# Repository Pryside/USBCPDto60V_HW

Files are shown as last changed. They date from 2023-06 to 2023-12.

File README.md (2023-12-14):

# USBCPDto60V_HW
the hardware portion of the USBC-PD Project

Software here: https://github.com/Pryside/USBCPDto60V

KiCad Project Files

Note: This is just a development Board, not the finished product. For testing purposes.

Done:
- ADC Voltage Measurement
- ADC Bi-Dir Current Measurement
- HRTimer D
- HRTimer C
- Full Bi-Directional Converter

To Do:
- Lower Noise on ADCs
- double check new Timer Routing
- Update ADC channel inputs
  


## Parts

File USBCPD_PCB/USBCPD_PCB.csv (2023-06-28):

# | Reference | Qty | Value | Footprint | DNP
1 | C1 | 1 | 1uF 25V | Capacitor_SMD:C_0603_1608Metric_Pad1.08x0.95mm_HandSolder
2 | C2 | 1 | A768MS277M1VLAS022 | CAPAE1030X1270N
3 | C3, C5, C6, C7 | 4 | GRM32DL8EL475KE07K | CAPC3225X220N
4 | C4 | 1 | 0.33uF 25V | Capacitor_SMD:C_0603_1608Metric_Pad1.08x0.95mm_HandSolder
5 | C8 | 1 | EEE-TP1K391M | EEEFK0J682AM
6 | C9, C12, C13, C16 | 4 | 1nF 25V | Capacitor_SMD:C_0402_1005Metric_Pad0.74x0.62mm_HandSolder
7 | C10, C14 | 2 | 4.7uF 25V | Capacitor_SMD:C_0603_1608Metric_Pad1.08x0.95mm_HandSolder
8 | C11, C15 | 2 | 0.1uF 25V | Capacitor_SMD:C_0603_1608Metric_Pad1.08x0.95mm_HandSolder
9 | D1 | 1 | T4F24AHM3_I | SODFL3718X108N
10 | D2 | 1 | 1.5SMBJ51CA-H | DIONM5436X244N
11 | IC1 | 1 | TMCS1108A3BQDRQ1 | SOIC127P600X175-8N
12 | IC2, IC3 | 2 | UCC27282QDRQ1 | SOIC127P600X175-8N
13 | IC4 | 1 | BAJ2CC0FP-E2 | BD750L5FPCE2
14 | J1, J2 | 2 | TB002-500-02BE | TB00250002BE
15 | JP1 | 1 | SolderJumper_2_Bridged | Jumper:SolderJumper-2_P1.3mm_Bridged_RoundedPad1.0x1.5mm
16 | L1 | 1 | SRP1038WA-150M | SRP1038WA150M
17 | LED1 | 1 | 150060BS75003 | 150060BS75003
18 | LED2 | 1 | 150060GS75003 | LEDC1608X80N
19 | LED3 | 1 | 150060SS75003 | 150060SS75003
20 | Q1, Q2, Q3, Q4 | 4 | SIR584DP-T1-RE3 | SamacSys_Parts:SIR584DPT1RE3
21 | R1, R2, R5, R6, R7 | 5 | 1R | Resistor_SMD:R_0603_1608Metric_Pad0.98x0.95mm_HandSolder
22 | R3, R4, R12, R15 | 4 | 3R | Resistor_SMD:R_0603_1608Metric_Pad0.98x0.95mm_HandSolder
23 | R8 | 1 | 100R | Resistor_SMD:R_0603_1608Metric_Pad0.98x0.95mm_HandSolder | DNP
24 | R9 | 1 | 900R | Resistor_SMD:R_0603_1608Metric_Pad0.98x0.95mm_HandSolder
25 | R10 | 1 | 2.8K | Resistor_SMD:R_0603_1608Metric_Pad0.98x0.95mm_HandSolder
26 | R11 | 1 | 100R | Resistor_SMD:R_0603_1608Metric_Pad0.98x0.95mm_HandSolder
27 | R13 | 1 | 28K | Resistor_SMD:R_0603_1608Metric_Pad0.98x0.95mm_HandSolder
28 | R14 | 1 | 1K62 | Resistor_SMD:R_0603_1608Metric_Pad0.98x0.95mm_HandSolder
29 | S1 | 1 | EVP-BDCC1A000 | EVPBDCC1A000
30 | TP1, TP2, TP3, TP4, TP5, TP6, TP7, TP8, TP9, TP10 | 10 | TestPoint | TestPoint:TestPoint_Pad_D1.0mm
31 | U1 | 1 | NUCLEO-G474RE | USBC_PD:ST_NUCLEO-G474RE
32 | Z1, Z2, Z3, Z4 | 4 | PDZ15B,115 | SOD2512X110N

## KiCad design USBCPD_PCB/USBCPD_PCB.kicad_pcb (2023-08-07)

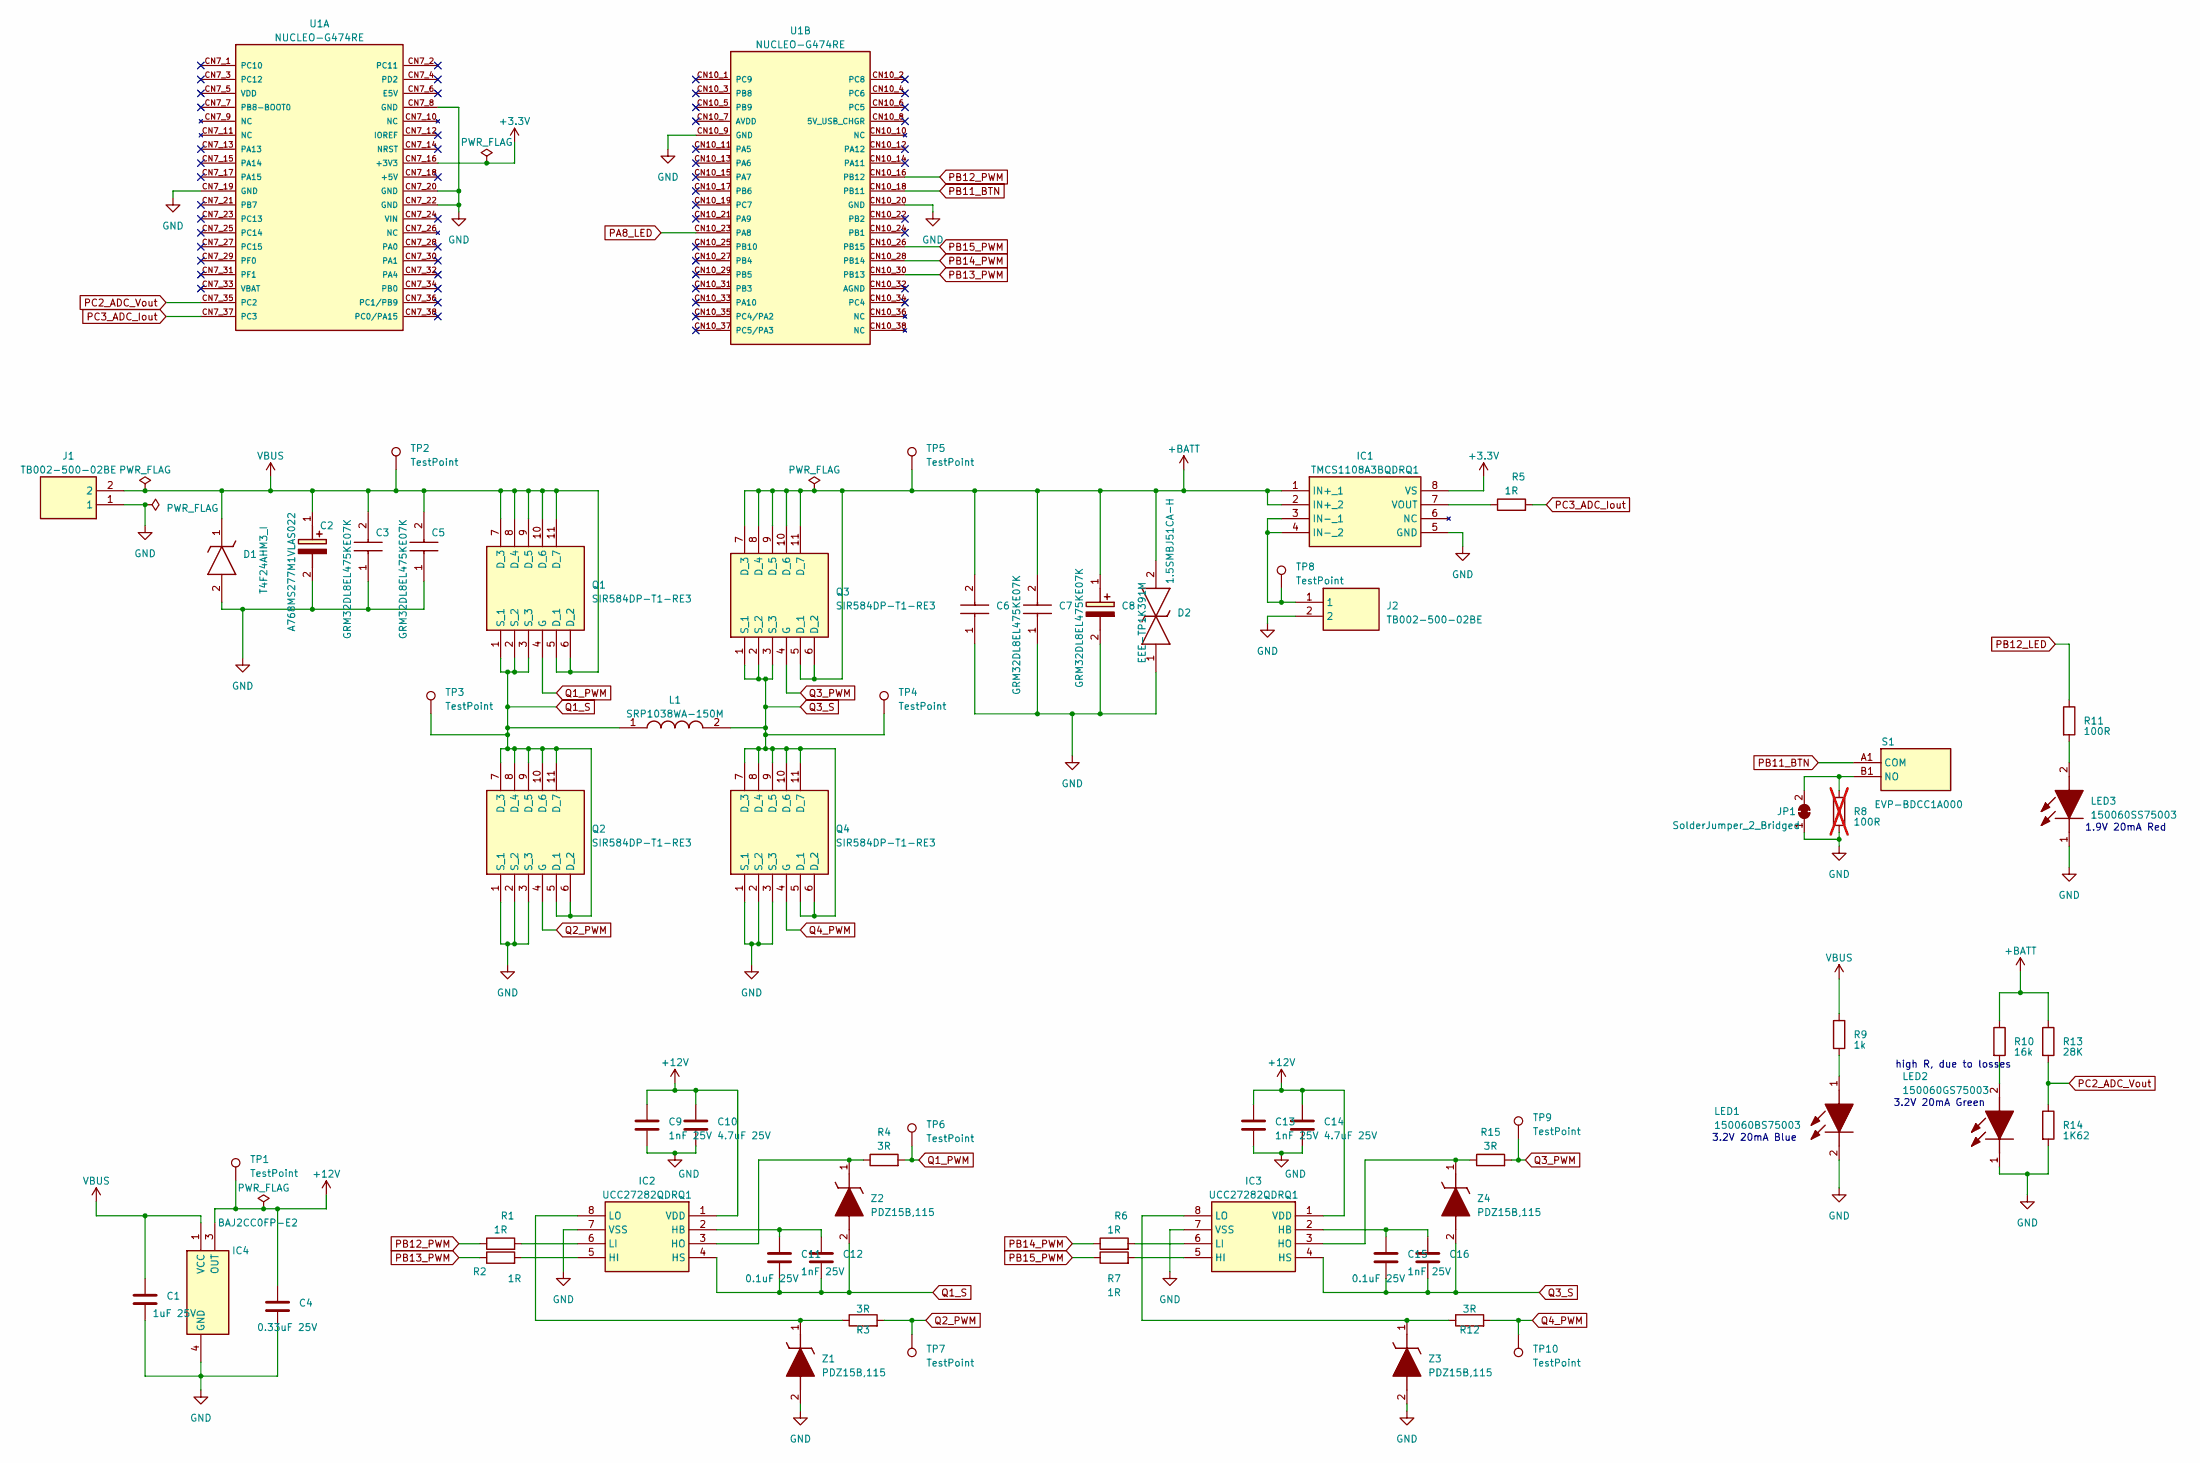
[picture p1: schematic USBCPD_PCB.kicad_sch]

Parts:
C1: 1uF 25V; C_0603_1608Metric_Pad1.08x0.95mm_HandSolder
C2: A768MS277M1VLAS022; CAPAE1030X1270N; Mouser Part Number 80-A768MS277M1VLAS22
C3, C5, C6, C7: GRM32DL8EL475KE07K; CAPC3225X220N; Mouser Part Number 81-GRM3DL8EL475KE07K
C4: 0.33uF 25V; C_0603_1608Metric_Pad1.08x0.95mm_HandSolder
C8: EEE-TP1K391M; EEEFK0J682AM; Mouser Part Number 667-EEE-TP1K391M
C9, C12, C13, C16: 1nF 25V; C_0402_1005Metric_Pad0.74x0.62mm_HandSolder
C10, C14: 4.7uF 25V; C_0603_1608Metric_Pad1.08x0.95mm_HandSolder
C11, C15: 0.1uF 25V; C_0603_1608Metric_Pad1.08x0.95mm_HandSolder
D1: T4F24AHM3_I; SODFL3718X108N; Manufacturer_Part_Number T4F24AHM3/I
D2: 1.5SMBJ51CA-H; DIONM5436X244N; Mouser Part Number 652-1.5SMBJ51CA-H
IC1: TMCS1108A3BQDRQ1; SOIC127P600X175-8N; Manufacturer_Part_Number TMCS1108A4BQDRQ1
IC2, IC3: UCC27282QDRQ1; SOIC127P600X175-8N; Mouser Part Number 595-UCC27282QDRQ1
IC4: BAJ2CC0FP-E2; BD750L5FPCE2; Mouser Part Number 755-BAJ2CC0FP-E2
J1, J2: TB002-500-02BE; TB00250002BE; Mouser Part Number 490-TB002-500-02BE
JP1: SolderJumper_2_Bridged; SolderJumper-2_P1.3mm_Bridged_RoundedPad1.0x1.5mm
L1: SRP1038WA-150M; SRP1038WA150M; Mouser Part Number 652-SRP1038WA-150M
LED1: 150060BS75003; Mouser Part Number 710-150060BS75003
LED2: 150060GS75003; LEDC1608X80N; Mouser Part Number 710-150060GS75003
LED3: 150060SS75003; Mouser Part Number 710-150060SS75003
Q1, Q2, Q3, Q4: SIR584DP-T1-RE3; SIR584DPT1RE3; Mouser Part Number 625-SIR582DP-T1-RE3
R1, R2, R5, R6, R7: 1R; R_0603_1608Metric_Pad0.98x0.95mm_HandSolder
R3, R4, R12, R15: 3R; R_0603_1608Metric_Pad0.98x0.95mm_HandSolder
R8: 100R; R_0603_1608Metric_Pad0.98x0.95mm_HandSolder; not fitted
R9: 1k; R_0603_1608Metric_Pad0.98x0.95mm_HandSolder
R10: 16k; R_0603_1608Metric_Pad0.98x0.95mm_HandSolder
R11: 100R; R_0603_1608Metric_Pad0.98x0.95mm_HandSolder
R13: 28K; R_0603_1608Metric_Pad0.98x0.95mm_HandSolder
R14: 1K62; R_0603_1608Metric_Pad0.98x0.95mm_HandSolder
S1: EVP-BDCC1A000; EVPBDCC1A000; Mouser Part Number 667-EVP-BDCC1A000
TP1, TP2, TP3, TP4, TP5, TP6, TP7, TP8, TP9, TP10: TestPoint; TestPoint_Pad_D1.0mm
U1: NUCLEO-G474RE; ST_NUCLEO-G474RE; PARTREV 13
Z1, Z2, Z3, Z4: PDZ15B,115; SOD2512X110N; Mouser Part Number 771-PDZ15B-T/R

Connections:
+3.3V: IC1.8 (VS), U1.CN7_16 (+3V3)
+12V: C4.1, C9.1, C10.1, C13.1, C14.1, IC2.1 (VDD), IC3.1 (VDD), IC4.3 (OUT), TP1.1
+BATT: C6.2, C7.2, C8.1 (+), D2.2, IC1.1 (IN+_1), IC1.2 (IN+_2), Q3.5 (D_1), Q3.6 (D_2), Q3.7 (D_3), Q3.8 (D_4), Q3.9 (D_5), Q3.10 (D_6), Q3.11 (D_7), R10.1, R13.1, TP5.1
GND: C1.2, C2.2 (-), C3.1, C4.2, C5.1, C6.1, C7.1, C8.2 (-), C9.2, C10.2, C13.2, C14.2, D1.2 (A), D2.1, IC1.5 (GND), IC2.7 (VSS), IC3.7 (VSS), IC4.4 (GND), J1.1, J2.2, JP1.1 (A), LED1.2 (K), LED2.1 (K), LED3.1 (K), Q2.1 (S_1), Q2.2 (S_2), Q2.3 (S_3), Q4.1 (S_1), Q4.2 (S_2), Q4.3 (S_3), R8.2, R14.2, U1.CN7_8 (GND), U1.CN7_19 (GND), U1.CN7_20 (GND), U1.CN7_22 (GND), U1.CN10_9 (GND), U1.CN10_20 (GND), Z1.2 (A), Z3.2 (A)
unnamed: IC1.3 (IN-_1), IC1.4 (IN-_2), J2.1, TP8.1
unnamed: IC1.7 (VOUT), R5.1
unnamed: C11.2, C12.1, IC2.2 (HB)
unnamed: IC2.5 (HI), R2.2
unnamed: IC2.3 (HO), R4.1, Z2.1 (K)
unnamed: IC2.6 (LI), R1.2
unnamed: IC2.8 (LO), R3.1, Z1.1 (K)
unnamed: C15.2, C16.1, IC3.2 (HB)
unnamed: IC3.5 (HI), R7.2
unnamed: IC3.3 (HO), R15.1, Z4.1 (K)
unnamed: IC3.6 (LI), R6.2
unnamed: IC3.8 (LO), R12.1, Z3.1 (K)
unnamed: JP1.2 (B), R8.1, S1.B1 (NO)
unnamed: LED1.1 (A), R9.2
unnamed: LED2.2 (A), R10.2
unnamed: LED3.2 (A), R11.2
PA8_LED: U1.CN10_23 (PA8)
PB11_BTN: S1.A1 (COM), U1.CN10_18 (PB11)
PB12_LED: R11.1
PB12_PWM: R1.1, U1.CN10_16 (PB12)
PB13_PWM: R2.1, U1.CN10_30 (PB13)
PB14_PWM: R6.1, U1.CN10_28 (PB14)
PB15_PWM: R7.1, U1.CN10_26 (PB15)
PC2_ADC_Vout: R13.2, R14.1, U1.CN7_35 (PC2)
PC3_ADC_Iout: R5.2, U1.CN7_37 (PC3)
Q1_PWM: Q1.4 (G), R4.2, TP6.1
Q1_S: C11.1, C12.2, IC2.4 (HS), L1.1, Q1.1 (S_1), Q1.2 (S_2), Q1.3 (S_3), Q2.5 (D_1), Q2.6 (D_2), Q2.7 (D_3), Q2.8 (D_4), Q2.9 (D_5), Q2.10 (D_6), Q2.11 (D_7), TP3.1, Z2.2 (A)
Q2_PWM: Q2.4 (G), R3.2, TP7.1
Q3_PWM: Q3.4 (G), R15.2, TP9.1
Q3_S: C15.1, C16.2, IC3.4 (HS), L1.2, Q3.1 (S_1), Q3.2 (S_2), Q3.3 (S_3), Q4.5 (D_1), Q4.6 (D_2), Q4.7 (D_3), Q4.8 (D_4), Q4.9 (D_5), Q4.10 (D_6), Q4.11 (D_7), TP4.1, Z4.2 (A)
Q4_PWM: Q4.4 (G), R12.2, TP10.1
VBUS: C1.1, C2.1 (+), C3.2, C5.2, D1.1 (K), IC4.1 (VCC), J1.2, Q1.5 (D_1), Q1.6 (D_2), Q1.7 (D_3), Q1.8 (D_4), Q1.9 (D_5), Q1.10 (D_6), Q1.11 (D_7), R9.1, TP2.1

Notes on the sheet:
3.2V 20mA Green
1.9V 20mA Red
high R, due to losses
3.2V 20mA Blue

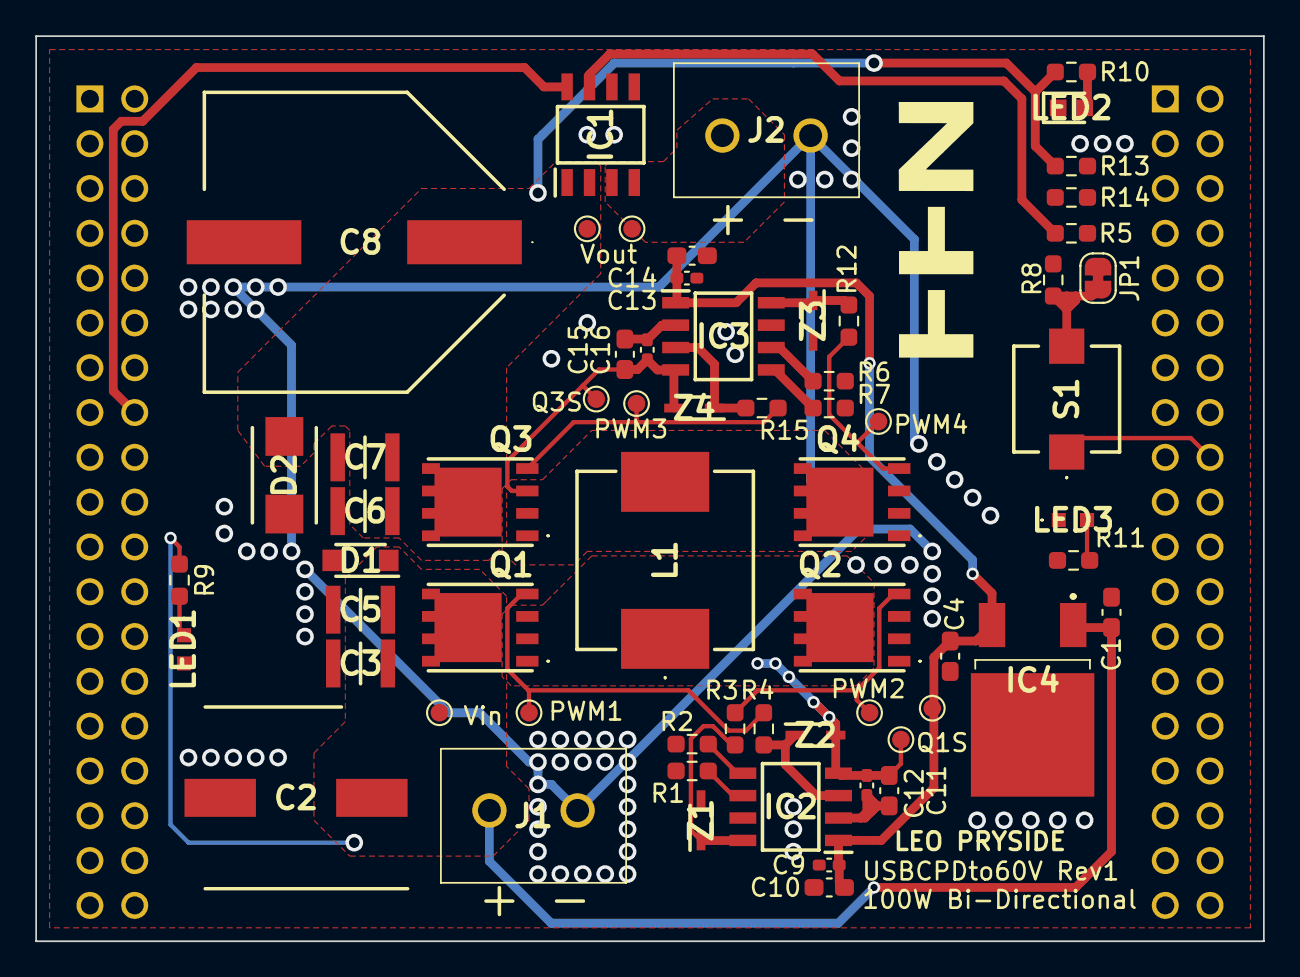
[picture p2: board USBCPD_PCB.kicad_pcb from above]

Board: 2 copper layers, 69.6 x 51.3 mm, 64 parts (0 on the bottom side), 34 nets.

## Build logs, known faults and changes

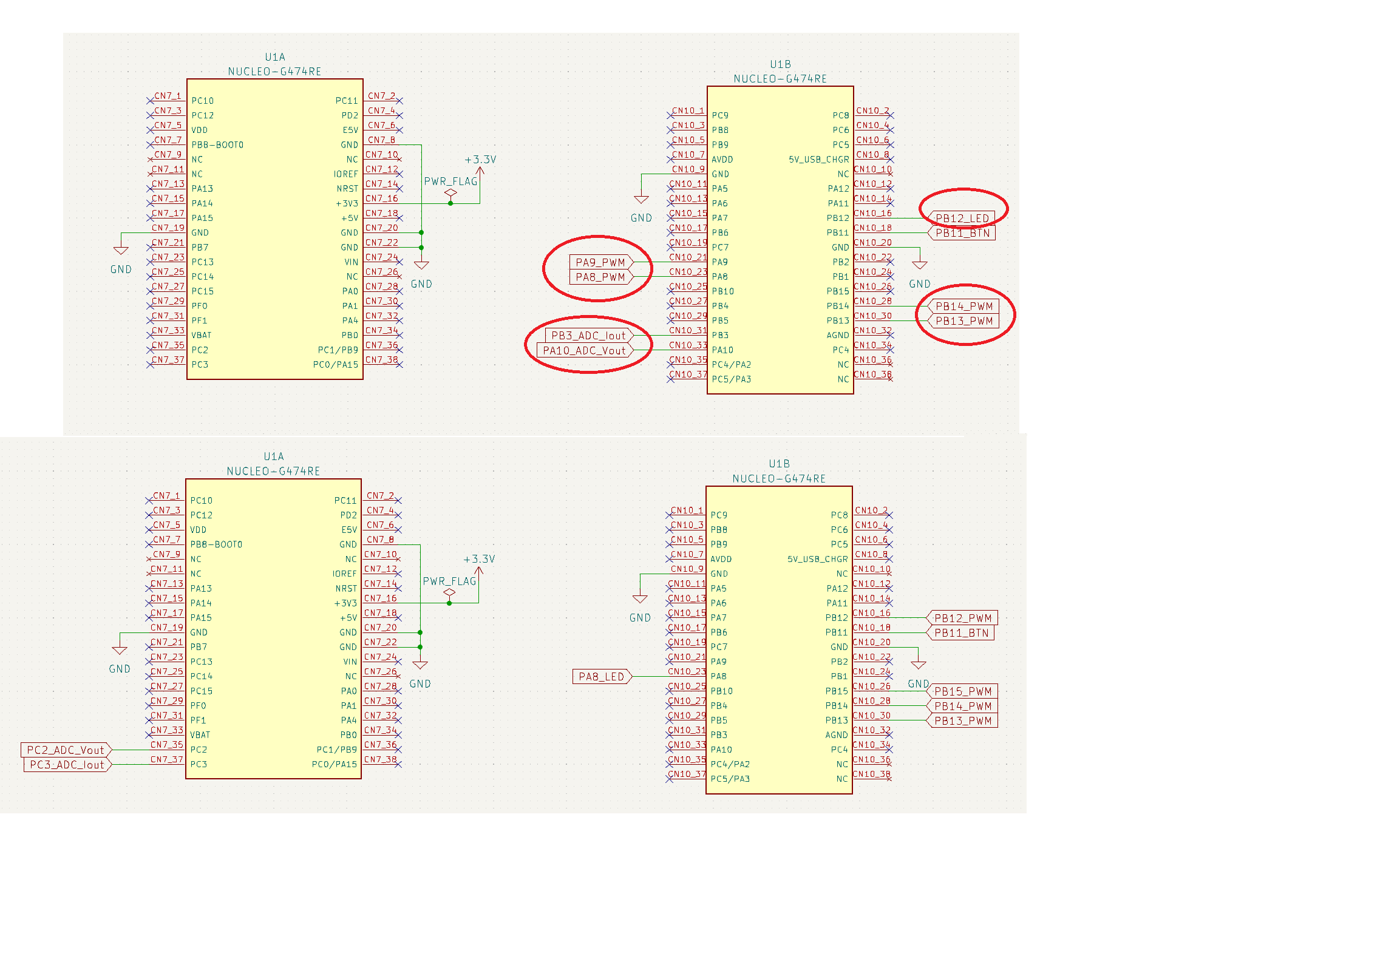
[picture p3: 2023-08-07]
Datasheets/changes.png

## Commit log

2023-05-21 library buildup
    [USBCPD_PCB.kicad_pcb, USBCPD_PCB.kicad_sch]
2023-05-22 quick library commit
    [USBCPD_PCB.kicad_sch]
2023-05-23 Added new Parts
    [USBCPD_PCB.kicad_sch]
2023-05-25 new components added
    [USBCPD_PCB.kicad_sch]
2023-05-31 added resistors, tvs and voltage control
    also wired up first changes
    [USBCPD_PCB.kicad_sch]
2023-06-01 added additional components
    [USBCPD_PCB.kicad_sch]
2023-06-02 Added Gate Driver Circuitry
    [USBCPD_PCB.kicad_sch]
2023-06-05 finished up main schematic
    finalized wiring, added leds with resistors, fixed ERC errors
    [USBCPD_PCB.kicad_pcb, USBCPD_PCB.kicad_sch]
2023-06-05 PCB layout, components sorted
    [USBCPD_PCB.kicad_pcb, USBCPD_PCB.kicad_sch]
2023-06-06 Schematic Fixes, Routing started
    Removed big zener diodes, replaced with smaller ones
    started routing
    [USBCPD_PCB.kicad_pcb, USBCPD_PCB.kicad_sch]
2023-06-06 more routing
    [USBCPD_PCB.kicad_pcb]
2023-06-07 libs added, routing finalized, fixed issues
    copied libs into folder, wrong wiring fixed, added test pads and silkscreen
    [USBCPD_PCB.kicad_pcb]
2023-06-07 pcb design fixes
    [USBCPD_PCB.kicad_pcb]
2023-06-07 drc fixes
    [USBCPD_PCB.kicad_pcb]
2023-06-10 gerber files created + small fixes
    [USBCPD_PCB-B_Cu.gbl, USBCPD_PCB-B_Mask.gbs, USBCPD_PCB-B_Paste.gbp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]
2023-06-28 tons of errors
    [USBCPD_PCB.csv, USBCPD_PCB.kicad_sch, USBCPD_PCB.xlsx]
2023-08-07 schematic rewire changes & hotfixes
    [USBCPD_PCB.kicad_pcb, USBCPD_PCB.kicad_sch]
